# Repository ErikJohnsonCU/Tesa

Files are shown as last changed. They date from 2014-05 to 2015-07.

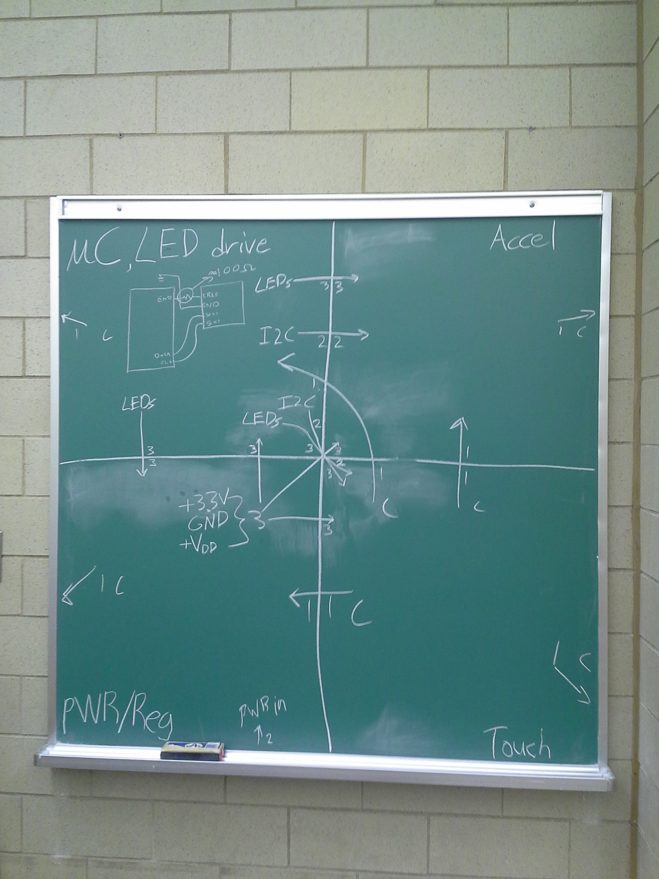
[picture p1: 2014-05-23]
Hardware/board_interconnects.jpg

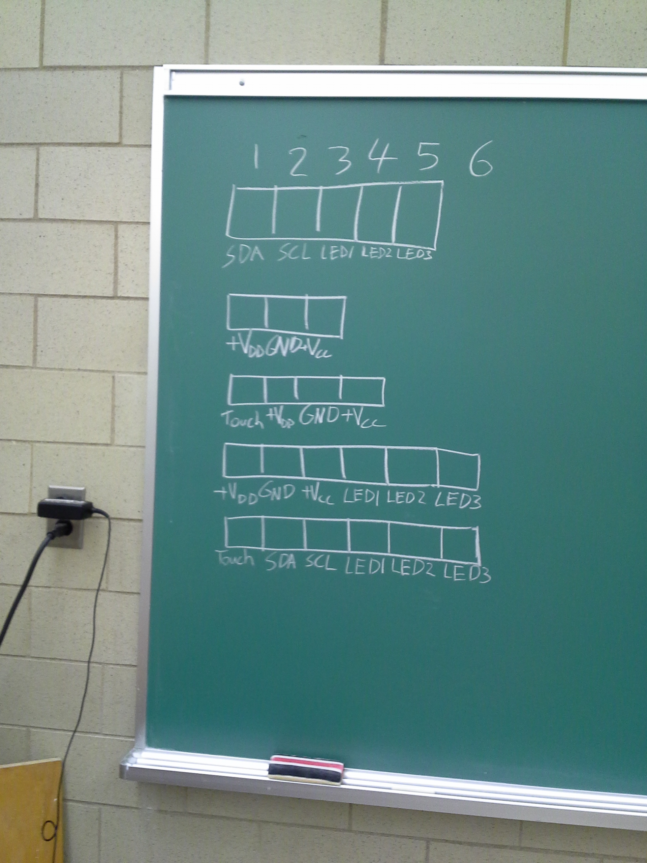
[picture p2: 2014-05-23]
Hardware/headers_order.jpg

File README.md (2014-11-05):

Tesa
====

Working board design and firmware for Tesa
==========================================

Please note I mis-ordered the 10k resistors as 2k resistors, these will still work as the value of the pull-up resistors on the reset line is very flexible.

Touch pads are numbered as follows:
Power -> 1
Micro -> 2
Accel -> 3
Touch -> 4

Leds are numbered as follows:
Micro -> 0 (rgb positions to be added)
Power -> 1 (rgb positions to be added)
Accel -> 2 (rgb positions to be added)
Touch -> 3 (rgb positions to be added)
r=3,g=2,b=1

Jumper resistor functions:
R105: connects PWRIN pin + to POWER pin 1 (use this to power uC via POWER header or distribute PWRIN pin + to other boards)
RECALL: POWER pin 1 drives LEDs
R108: connects POWER pin 3 to board's Vcc (+3.3V) (use this to run uC off external +3.3V or distribute +3.3V to other boards)

Similar work by other OH designers:
http://www.ofbrooklyn.com/2014/09/6/building-pulse-bloom-biofeedback-burning-man-2014/

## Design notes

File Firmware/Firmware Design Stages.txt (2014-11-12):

Firmware Design Stages
======================

Modular Code Development
========================
1. LED driver (shift register)
2. Touch (I2C)
3. Accelermeter (I2C)

Combination Stage
===================
1. State flow diagram
2.

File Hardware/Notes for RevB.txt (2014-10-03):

Traces
======
Signal lines: 8 mil
Power lines: 12 mil

Text
====
Header names: 50(12%)
Header designations: 36(10%)
Components: 25(8%)

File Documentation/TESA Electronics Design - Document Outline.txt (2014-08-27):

TESA Electronics Design
=======================
1.0 Motivation
2.0 Requirements
	2.1 Prototype
	2.2 Consumer Product
3.0 Prototype Design
	3.1 Hardware
		3.1.1 Microcontroller board
		3.1.2 Accelerometer board
		3.1.3 Touch driver board
		3.1.4 Power distribution board
	3.2 Firmware
4.0 Consumer Product Design
	4.1 Hardware
		4.1.1 Base discrete unit hardware
		4.1.2 Pro discrete unit hardware
		4.1.3 Hub hardware
	4.2 Firmware
		4.2.1 Base discrete unit firmware
		4.2.2 Pro discrete unit firmware
		4.2.3 Hub firmware
5.0 Project Timeline

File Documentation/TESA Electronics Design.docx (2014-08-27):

# Motivation

To fulfill a contract committed to creating a home lighting system.

# Requirements

## Prototype

- Tap-on/off capability
- Ability to connect with other units and base
- Each face supports variation in brightness
- Detection of present orientation/change in orientation

## Consumer Product

### Base Unit

- Tap-on/off capability
- Ability to connect with other units and base
- Each face supports variation in brightness
- Communication with hub and other units

### Pro Unit

- Tap-on/off capability
- Ability to connect with other units and base
- Each face supports variation in brightness
- Detection of present orientation/change in orientation
- Communication with hub and other units
- Ability to charge once connected to the hub

### Hub

- Communication with units
- Ability to charge pro units

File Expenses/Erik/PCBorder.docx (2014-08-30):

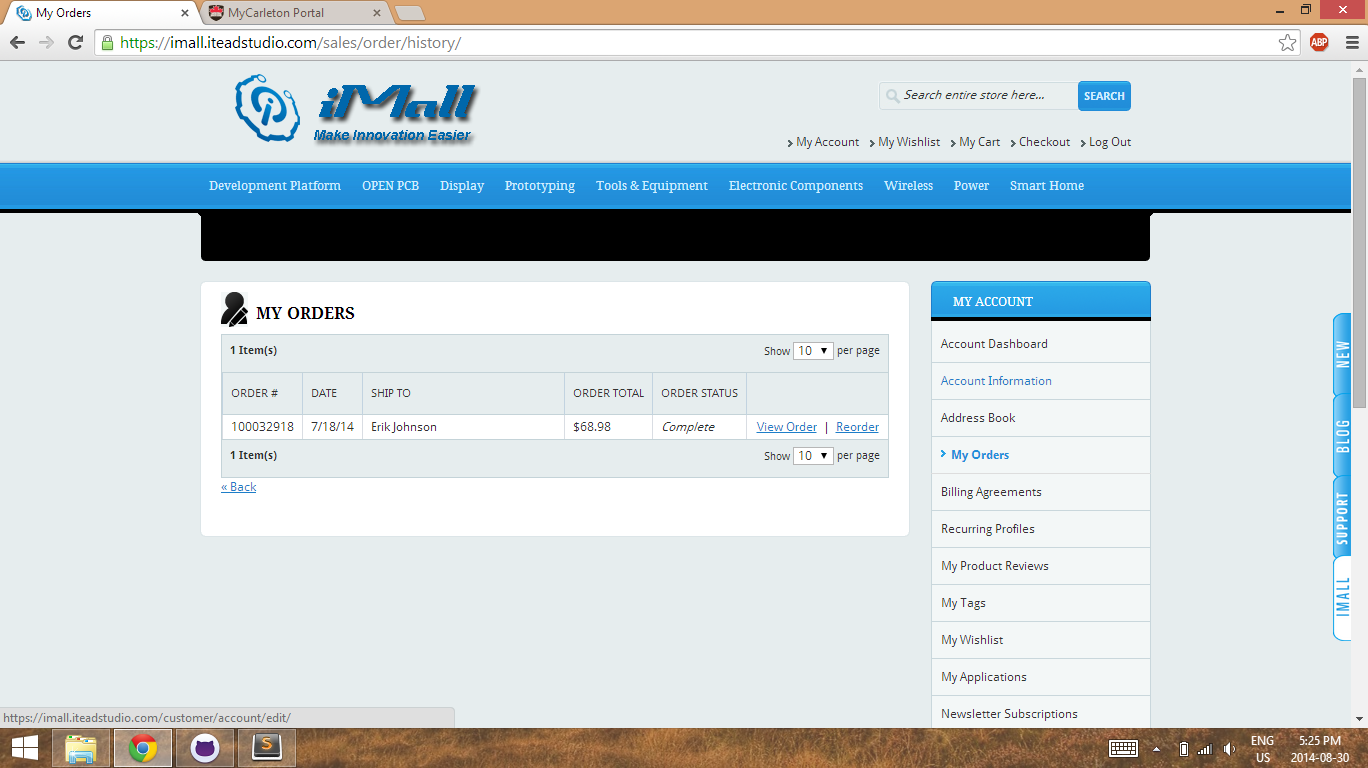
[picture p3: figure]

Expense total: $ 68.98

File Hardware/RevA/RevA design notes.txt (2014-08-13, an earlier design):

Radius of board cut is: 2.436 cm or 0.96"

Size of text is 40 (ratio 10 %) for refdes, and 60 (ratio 16 %) for header names

Size of signal traces is 8 mils
Size of power (LED, not Vcc or +3.3V) traces is 16 mils

Touch pads are numbered as follows:
Power -> 1
Micro -> 2
Accel -> 3
Touch -> 4

Leds are numbered as follows:
Power -> 0 (rgb positions to be added)
Micro -> 1 (rgb positions to be added)
Accel -> 2 (rgb positions to be added)
Touch -> 3 (rgb positions to be added)
r=3,g=2,b=1

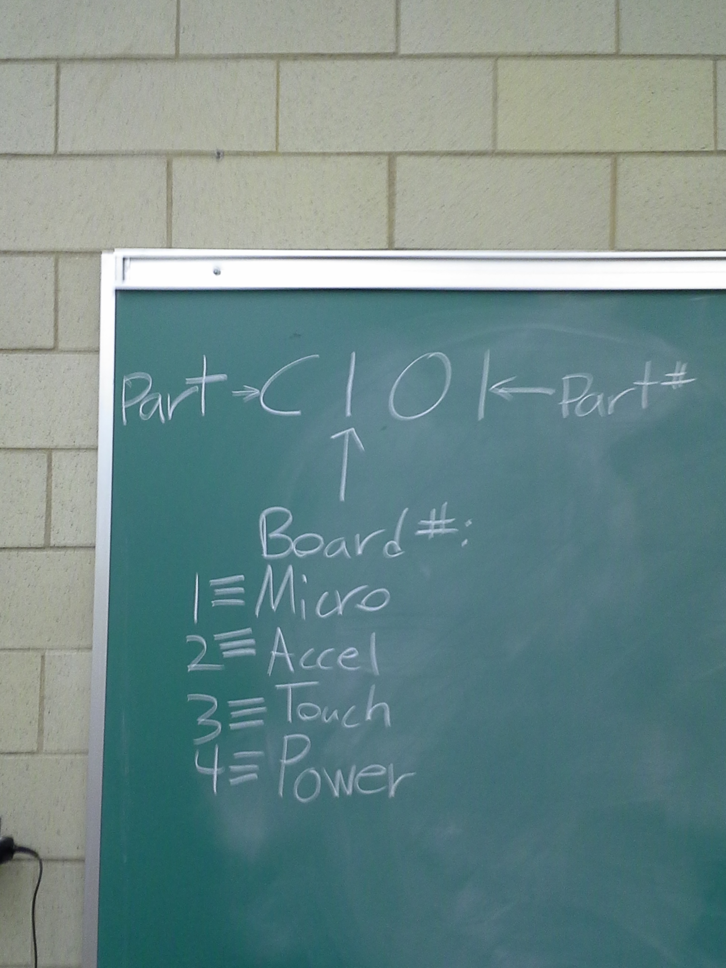
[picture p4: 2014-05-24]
Hardware/part_naming_conventions.jpg

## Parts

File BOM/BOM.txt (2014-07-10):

BOM

-AtMega32u4
-AT42QT1070
-MMA8452Q
-TLC59711
-4.7u cap
-0.1u cap x6
-1u cap x2
-4.7k res x2
-22 res x2
-MF-MSMF050-2
-1.42k (and surrounding values)
-10u cap
-the regulator
-20k res x5
-1 pin through-hole header x8
-2 pin through-hole header x2
-3 pin through-hole header x2
-4 pin through-hole header x2
-5 pin through-hole header x1
-6 pin through-hole header x2
-6 pin SMD header x4
-SMD micro USB plug

total # of headers: 43 (order 45)

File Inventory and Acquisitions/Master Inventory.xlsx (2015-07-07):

Inventory for TESA Project
Last updated: Nov. 4/14
Updated by: Erik
 |  | Resistors in ohms, capacitors in farads, fuses in amperes, resonators in Hz, regulators in volts,
Component type | Stock | Value | Refdes(es) | Footprint | Supplier | Supplier PN | Manufacturer | Manufacturer PN | Pricing (10/100/500) | Active in project? | ROHS
Capacitor | 3 | 1u | C104 | SMD_0603 | Mouser | 81-GRM188R61E105KA12 | Murata | GRM188R61E105KA12D | 0.031/0.027/0.019 | Yes | compliant
Resistor | 8 | 4.7k | R101,R102 | SMD_0603 | Mouser | 667-ERJ-3GEYJ472V | Panasonic | ERJ-3GEYJ472V | 0.014/0.01/0.007 | Yes | exemption
Fuse | 6 | 0.5A | F101 | SMD_1812 | Mouser | 652-MF-MSMF050-2 | Bourns | MF-MSMF050-2 | 0.201/0.177/0.139 | Yes
Resonator | 4 | 8M | X101 | CSTCE | Mouser | 81-CSTCE8M00G15C99R0 | Murata | CSTCE8M00G15C99-R0 | 0.503/0.477/-- | Yes | compliant
Resistor | 21 | 20k | R104,301,R302,R303,R304,R305 | SMD_0603 | Mouser | 667-ERJ-3GEYJ203V | Panasonic | ERJ-3GEYJ203V | 0.014/0.01/0.007 | Yes | exemption
Resistor | 10 | 1.4k | R103 | SMD_0603 | Mouser | 667-ERJ-3EKF1401V | Panasonic | ERJ-3EKF1401V | 0.018/0.01/0.007 | Yes | exemption
Resistor | 12 | 22 | N/A | SMD_0603 | Mouser | 667-ERJ-3GEYJ220V | Panasonic | ERJ-3GEYJ220V | 0.014/0.009/0.007 | NO (prev R105,R106) | exemption
Resistor | 10 | 1.2k | R103 | SMD_0603 | Mouser | 667-ERJ-3GEYJ122V | Panasonic | ERJ-3GEYJ122V | 0.024/0.012/0.007 | Yes | exemption
Resistor | 10 | 1.0k | R103 | SMD_0603 | Mouser | 667-ERJ-3EKF1001V | Panasonic | ERJ-3EKF1001V | 0.017/0.011/0.008 | Yes | exemption
Capacitor | 31 | 0.1u | C101,C102,C103,C107,C201,C202,C301,C401 | SMD_0603 | Mouser | 81-GRM39X104K16 | Murata | GRM188R71C104KA01D | 0.016/0.01/0.007 | Yes | compliant
Capacitor | 12 | 0.01u | N/A | SMD_0402 | Mouser | 81-GRM36X103K25 | Murata | GRM155R71E103KA01D | 0.009/0.006/0.005 | NO
Regulator | 5 | 3.3V | Q401 | TO220 | Mouser | 511-LD1117V33C | STMicroelectronics | LD1117V33C | 0.528/0.35/-- | Yes | compliant
LEDs | 70 | N/A | LED | PLCC4 | Mouser | 941-CLA1BWKWXD0F0DY3 | Cree | CLA1B-WKW-XD0F0DY3 | 0.289/0.253/0.229 | Yes | compliant
Micro-controller | 7 | N/A | U101 | TQFP44 |  |  | Atmel | AtMega32U4 |  | Yes
Touch driver | 4 | N/A | U301 | SOIC14 | Mouser | 556-AT42QT1070-SSU | Atmel | AT42QT1070-SSU | 1.77/1.27/1.19 | Yes | compliant
Accelerometer | 4 | N/A | U201 | QFN16 | Mouser | 841-MMA8452QR1 | Freescale | MMA8452QR1 | 1.48/0.965/-- | Yes | exemption
microB USB Female | 6 | N/A | N/A | N/A | Mouser | 649-10118192-0001LF | PCI | 10118192-0001LF | 0.336/0.29/0.25 | Yes | compliant
Pin headers (TH) | 14x2 | N/A | N/A | N/A | Mouser | 653-XG8S-0231 | Omron | XG8S-0231 | for 25: 0.129/0.106/0.079 | Yes | compliant
Pin headers (SMD) | 22X6 | N/A | N/A | N/A | Digikey | S1013E-06-ND | Sullins | GEC06SABN-M30 | 1.205/0.9924/0.78446 | Yes | compliant
Board | 10 | micro-A | micro (1) | N/A | Itead | N/A | N/A | N/A | N/A | Yes
Board | 10 | accel | accel (2) | N/A | Itead | N/A | N/A | N/A | N/A | Yes
Board | 12 | touch | touch (3) | N/A | Itead | N/A | N/A | N/A | N/A | Yes
Board | 11 | power | power (4) | N/A | Itead | N/A | N/A | N/A | N/A | Yes
Capacitor | 10 | 10u | C106,C203,C402 | SMD_0603 | Mouser | 963-AMK107ABJ106MAHT | Taiyo Yuden | AMK107ABJ106MAHT | 0.075/0.043/-- | Yes | compliant
LED driver | 4 | N/A | U102 | HTSSOP20 | Mouser | 595-TLC59711PWP | TI | TLC59711PWP | 4.23/3.46/2.81 | Yes | compliant
Capacitor | 11 | 10u | C106,C203,C402 | SMD_0603 | Mouser | 81-GRM18R60J475KE19D | Murata | GRM188R60J106ME47D | 0.063/0.063/-- | Yes | compliant
Capacitor | 10 | 4.7u | C203 | SMD_0603 | Mouser | 81-GRM18R60J475KE19D | Murata | GRM188R60J475KE19D | 0.063/0.035/-- | Yes | compliant
Microcontroller | 3 | N/A | U101 | TQFP_32 | Mouser | 556-ATMEGA328P-AU | Atmel | ATMEGA328P-AU | 3.64/2.74/2.58 | Yes | compliant
Resonator | 4 | 16M | X101 | CSTCE | Mouser | 81-CSTCE16M0V53-R0 | Murata | CSTCE16M0V53-R0 | 0.434/0.35/-- | Yes | compliant
Resistor | 8 | 2k (mistake) | R104 | SMD_0603 | Mouser | 71-CRCW0603-2.0K-E3 | Vishay | CRCW06032K00FKEA | 0.016/0.012/-- | Yes | exemption
Resistor | 11 | 180 | R106,R107 | SMD_0603 | Mouser | 71-CRCW0603J-180-E3 | Vishay | CRCW0603180RJNEA | 0.012/0.01/-- | Yes | exemption
Capacitor | 13 | 0.01u | C105 | SMD_0603 | Mouser | 77-VJ0603Y103KXAAC | Vishay | VJ0603Y103KXAAC | 0.06/0.036/0.03 | Yes | compliant
Resistor | 11 | 0 | R105,R108 | SMD_0603 | Mouser | 71-CRCW0603-0-E3 | Vishay | CRCW06030000Z0EA | 0.012/0.01/-- | Yes | exemption
Regulator | 3 | 3.3V | U103 | SOT-23-5 | Mouser | 595-LP2985-33DBVR | TI | LP2985-33DBVR | 0.578/0.43/0.317 | Yes | compliant
Pin Headers | 5 | N/A | N/A | N/A | Mouser | 517-9611106404AR | 3M | 961110-6404-AR | --/0.437/0.412 | Yes | compliant
Red LED | 9 | N/A | LED5 | SMD_0603 | Mouser | 710-150060RS75000 | Wurth | 150060RS75000 | 0.253/0.232/-- | Yes | compliant
Green LED | 8 | N/A | LED4 | SMD_0603 | Mouser | 710-150060VS75000 | Wurth | 150060VS75000 | 0.253/0.232/-- | Yes | compliant
Board | 19 | micro-B | micro (1) | N/A | Itead | N/A | N/A | N/A | N/A | Yes

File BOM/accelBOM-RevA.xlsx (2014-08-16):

TESA - Industrial Design Project - Summer 2014
Board: accel
Revision: A
Bill of Materials
Quantity | Refdes | Value | Footprint/Package | Specification | Supplier | Supplier PN | Manufacturer | Manufacturer PN | Price in $ (10/100/500)
1 | U201 | MMA8452Q | QFN-16 |  | Mouser | 841-MMA8452QR1 | Freescale | MMA8452QR1 | 1.44/0.857/-
1 | C203 | 4.7u | SMD_0603 |  | Mouser | 81-GRM18R60J475KE19D | Murata | GRM188R60J475KE19D | 0.061/0.035/--
2 | C201,C202 | 0.1u | SMD_0603 |  | Mouser | 81-GRM39X104K16 | Murata | GRM188R71C104KA01D | 0.023/0.018/0.015
3 | LED1,LED2,LED3 |  |  |  | Mouser | 941-CLA1BWKWXD0F0DY3 | Cree | CLA1B-WKW-XD0F0DY3 | 0.282/0.247/0.223
N/A | TH hdr | 12 pins |  |  | Mouser | 653-XG8S-0231 | Omron | XG8S-0231 | for 25: 0.129/0.106/0.079

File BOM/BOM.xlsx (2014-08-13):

Micro |  | Accel |  | Touch |  | Power
Refdes | Part | Refdes | Part | Refdes | Part | Refdes | Part
U101 | AtMega32U4 | U201 | MMA8452Q | U301 | AT42QT1070 | Q401
R101 | 4.7k | C201 | 0.1u | R301 | 20k | C401 | 0.1u
R102 | 4.7k | C202 | 0.1u | R302 | 20k | C402 | 10u
R103 | 1.42k (or close value) | C203 | 4.7u | R303 | 20k | 1pin TH hdr | 16pin hdr total
R104 | 22 | LED1 |  | R304 | 20k | 2pin TH hdr
R105 | 22 | LED2 |  | R305 | 20k | 3pin TH hdr
F101 | MF-MSMF050-2 (check rating) | LED3 |  | C301 | 0.1u | 4pin TH hdr
C101 | 0.1u | 1pin TH hdr | 12pin hdr total | LED1 |  | 6pin TH hdr
C102 | 1u | 1pin TH hdr |  | LED2
C103 | 1u | 2pin TH hdr |  | LED3
C104 | 0.1u | 3pin TH hdr |  | 1pin TH hdr | 13pin hdr total
X101 | CSTCE8M00G55-R0 | 5pin TH hdr |  | 1pin TH hdr
LED1 |  |  |  | 1pin TH hdr
LED2 |  |  |  | 4pin TH hdr
LED3 |  |  |  | 6pin Th hdr
uB USB plug
6pin SMD hdr
6pin SMD hdr
6pin SMD hdr
6pin SMD hdr
1pin TH hdr
U102 | TLC59711

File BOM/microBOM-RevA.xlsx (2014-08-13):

TESA - Industrial Design Project - Summer 2014
Board: micro
Revision: A
Bill of Materials
Quantity | Refdes | Value | Footprint/Package | Specification | Supplier | Supplier PN | Manufacturer | Manufacturer PN | Price in $ (10/100/500)
1 | U101 | AtMega32U4 | TQFP-44 |  |  |  | Atmel | AtMega32U4
2 | R101,R102 | 4.7k | SMD_0603 |  | Mouser | 667-ERJ-3GEYJ472V | Panasonic | ERJ-3GEYJ472V | 0.014/0.009/0.007
1 | R103 | 1k | SMD_0603 |  | Mouser | 667-ERJ-3EKF1001V | Panasonic | ERJ-3EKF1001V | 0.016/0.011/0.008
1 | R103 | 1.2k | SMD_0603 |  | Mouser | 667-ERJ-3GEYJ122V | Panasonic | ERJ-3GEYJ122V | 0.023/0.012/0.007
1 | R103 | 1.4k | SMD_0603 |  | Mouser | 667-ERJ-3EKF1401V | Panasonic | ERJ-3EKF1401V | 0.018/0.009/0.007
1 | R103 | 1.6k | SMD_0603 |  | Mouser | 667-ERJ-3GEYJ162V | Panasonic | ERJ-3GEYJ162V | 0.023/0.012/0.007
1 | R103 | 1.8k | SMD_0603 |  | Mouser | 667-ERJ-3GEYJ182V | Panasonic | ERJ-3GEYJ182V | 0.023/0.012/0.007
2 | R104,R105 | 22 | SMD_0603 |  | Mouser | 667-ERJ-3GEYJ220V | Panasonic | ERJ-3GEYJ220V | 0.014/0.009/0.007
1 | F101 | MF-MSMF050-2 | SMD_1812 | 1A trip | Mouser | 652-MF-MSMF050-2 | Bourns | MF-MSMF050-2 | 0.201/0.177/0.139
2 | C101,C104 | 0.1u | SMD_0603 |  | Mouser | 81-GRM39X104K16 | Murata | GRM188R71C104KA01D | 0.023/0.018/0.015
2 | C102,C103 | 1u | SMD_0603 |  | Mouser | 81-GRM188R61E105KA12 | Murata | GRM188R61E105KA12D | 0.031/0.026/0.019
1 | X101 | CSTCE8M00G55-R0 | CSTCE |  | Mouser | 81-CSTCE8M00G15C99R0 | Murata | CSTCE8M00G15C99-R0 | 0.49/0.465/--
3 | LED1,LED2,LED3 |  | PLCC-4 |  | Mouser | 941-CLA1BWKWXD0F0DY3 | Cree | CLA1B-WKW-XD0F0DY3 | 0.282/0.247/0.223
1 | uB USB Female |  |  |  | Mouser | 649-10118192-0001LF | PCI | 10118192-0001LF | 0.336/0.29/0.25
4 | 6 pin SMD hdr |  |  |  | Digikey | S1013E-06-ND | Sullins | GEC06SABN-M30 | 1.205/0.9924/0.78446
N/A | TH hdr | 1 pin |  |  | Mouser | 653-XG8S-0231 | Omron | XG8S-0231 | for 25: 0.129/0.106/0.079
1 | U102 | TLC59711 | HTSSOP-20 |  | Mouser | 595-TLC59711PWP | TI | TLC59711PWP | 4.12/3.37/2.47

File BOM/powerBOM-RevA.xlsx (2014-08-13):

TESA - Industrial Design Project - Summer 2014
Board: power
Revision: A
Bill of Materials
Quantity | Refdes | Value | Footprint/Package | Specification | Supplier | Supplier PN | Manufacturer | Manufacturer PN | Price in $ (10/100/500)
1 | Q401 | 3.3V | LD1117-TO-220 |  | Mouser | 511-LD1117V33C | STMicroelectronics | LD1117V33C | 0.775/0.514/0.341
1 | C401 | 0.1u | SMD_0603 |  | Mouser | 81-GRM39X104K16 | Murata | GRM188R71C104KA01D | 0.023/0.018/0.015
1 | C402 | 10u | SMD_0603 |  | Mouser | 81-GRM188R60J106ME47 | Murata | GRM188R60J106ME47D | 0.225/0.135/--
3 | LED1,LED2,LED3 |  |  |  | Mouser | 941-CLA1BWKWXD0F0DY3 | Cree | CLA1B-WKW-XD0F0DY3 | 0.282/0.247/0.223
N/A | TH hdr | 16 pins |  |  | Mouser | 653-XG8S-0231 | Omron | XG8S-0231 | for 25: 0.129/0.106/0.079

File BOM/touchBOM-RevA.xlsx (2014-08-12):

TESA - Industrial Design Project - Summer 2014
Board: touch
Revision: A
Bill of Materials
Quantity | Refdes | Value | Footprint/Package | Specification | Supplier | Supplier PN | Manufacturer | Manufacturer PN | Price in $ (10/100/500)
1 | U301 | AT42QT1070 | SOIC-14 |  | Mouser | 556-AT42QT1070-SSU | Atmel | AT42QT1070-SSU | 1.55/0.969/-
5 | R301,R302,R303,R304,R305 | 20k | SMD_0603 |  | Mouser | 667-ERJ-3GEYJ203V | Panasonic | ERJ-3GEYJ203V | 0.014/0.009/0.007
1 | C301 | 0.1u | SMD_0603 |  | Mouser | 81-GRM39X104K16 | Murata | GRM188R71C104KA01D | 0.023/0.018/0.015
3 | LED1,LED2,LED3 |  |  |  | Mouser | 941-CLA1BWKWXD0F0DY3 | Cree | CLA1B-WKW-XD0F0DY3 | 0.282/0.247/0.223
N/A | TH hdr | 13 pins |  |  | Mouser | 653-XG8S-0231 | Omron | XG8S-0231 | for 25: 0.129/0.106/0.079

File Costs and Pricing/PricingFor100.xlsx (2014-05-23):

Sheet: Without USB
Price (per unit for 100) | Price (extended) | Description | Part | Quantity (for 100 units) | Supplier | Supplier ref | Schem ref des
1.93 | 193 | Micro Controller | ATMega328 | 100 | Mouser | 556-ATMEGA328-AU
0.99 | 99 | Touch sensor | AT42QT1070 | 100 | Mouser | 556-AT42QT1070-SSU
2.94 | 294.35 | LED driver | TLC59711 | 100 | Digikey | 296-36745-1-ND
2.64 | 264 | LEDs | CLA1B-WKW-XD0F0E33 | 1200 | Digikey | CLA1B-WKW-XD0F0E33TR-ND
2.5 | 100 | PCBs |  | 400 | ITEAD | N/A
0.876 | 87.6 | Accelerometer | MMA8452QR1 | 100 | Mouser | 841-MMA8452QR1
Price of Unit | Price of 100 Units
11.876 | 1037.95

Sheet: With USB
Price (per unit for 100) | Price (extended) | Description | Part | Quantity (for 100 units) | Supplier | Supplier ref | Schem ref des
4.21 | 421 | MicroController (USB capable) | AtMega32U4-AU | 100 | Mouser | 556-ATMEGA32U4-AU
0.99 | 99 | Touch sensor | AT42QT1070 | 100 | Mouser | 556-AT42QT1070-SSU
2.94 | 294.35 | LED driver | TLC59711 | 100 | Digikey | 296-36745-1-ND
2.64 | 264 | LEDs | CLA1B-WKW-XD0F0E33 | 1200 | Digikey | CLA1B-WKW-XD0F0E33TR-ND
2.5 | 100 | PCBs |  | 400 | ITEAD | N/A
0.876 | 87.6 | Accelerometer | MMA8452QR1 | 100 | Mouser | 841-MMA8452QR1
Price of Unit | Price of 100 Units
14.156 | 1265.95

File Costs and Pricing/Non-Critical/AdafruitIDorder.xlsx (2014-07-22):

Item | Use | Price (for indicated quantity) | Adafruit ref
TLC59711 - LED Driver SPI | PWM LED Driver w/ 16 bit res | 7.5 | 1455
Trinket - Mini MCU 3.3V logic | Prototype MCU | 7.95 | 1500
Tilt ball switch | Possibly bets than accel (cheaper) | 2 | 173
Piezo element | Possibly tap detection? | 0.95 | 1739
 | Subtotal | 18.4
 | TOTAL PRICE (w taxes and shipping) | ~25

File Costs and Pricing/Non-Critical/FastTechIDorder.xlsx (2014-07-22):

Item | Use | Price (for indicated quantity) | FastTech ref
Tap/Knock Sensor | Tap detection | 6.72 | 1585704
 | Subtotal | 6.72
 | TOTAL PRICE (w taxes and shipping)

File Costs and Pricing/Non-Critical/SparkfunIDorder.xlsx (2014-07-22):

Item | Use | Price (for indicated quantity) | Sparkfun ref
TLC 5940 - PWM Driver | For driving the leds | 5.95 | COM10136
LED RGB clear x2 | Lighting | 3.9 | COM00105
LED RGB diffuse x2 | Lighting | 3.9 | COM09264
Piezo element | Possibly tap sensor? | 1.5 | SEN10293
AVR 8 pin ATtiny85 | Cheap MCU | 2.84 | COM09378
MMA8452Q accel breakout | Gravity sensing | 9.95 | SEN10955
AVR 14 pin ATtiny84 | Cheap MCU | 2.95 | COM11232
 | Subtotal | 30.99
 | TOTAL PRICE (w taxes and shipping) | 30.99

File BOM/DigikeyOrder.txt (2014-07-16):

DigiKey

Product Number			Quantity
S1013E-06-ND			24
MCP6002-I/P-ND			3

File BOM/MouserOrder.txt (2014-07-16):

Mouser

Product Number			Quantity
556-AT42QT1070-SSU		6
667-ERJ-3GEYJ203V		30
81-GRM39X104K16			42
941-CLA1BWKWXD0F0DY3		72
667-ERJ-3GEYJ472V		12
667-ERJ-3GEYJ220V		12
652-MF-MSMF050-2		6
81-GRM188R61E105KA12		12
81-CSTCE8M00G15C99R0		10
649-10118192-0001LF		6
653-XG8S-0231			14
841-MMA8452QR1			6
81-GRM36X103K25			12
511-LD1117V33C			6
667-ERJ-U03F1001V		10
667-ERJ-3GEYJ122V		10
667-ERJ-3EKF1401V		10
667-ERJ-3GEYJ162V		10
667-ERJ-3GEYJ182V		10

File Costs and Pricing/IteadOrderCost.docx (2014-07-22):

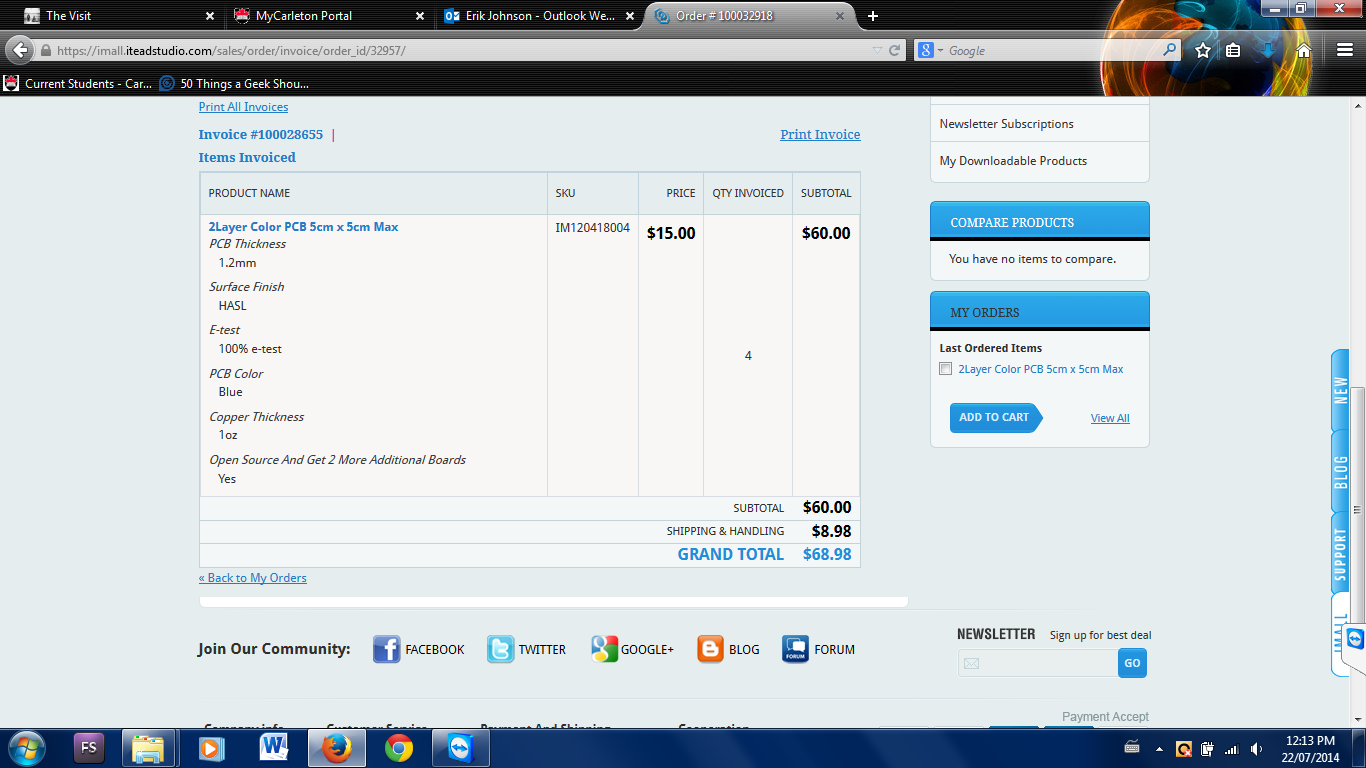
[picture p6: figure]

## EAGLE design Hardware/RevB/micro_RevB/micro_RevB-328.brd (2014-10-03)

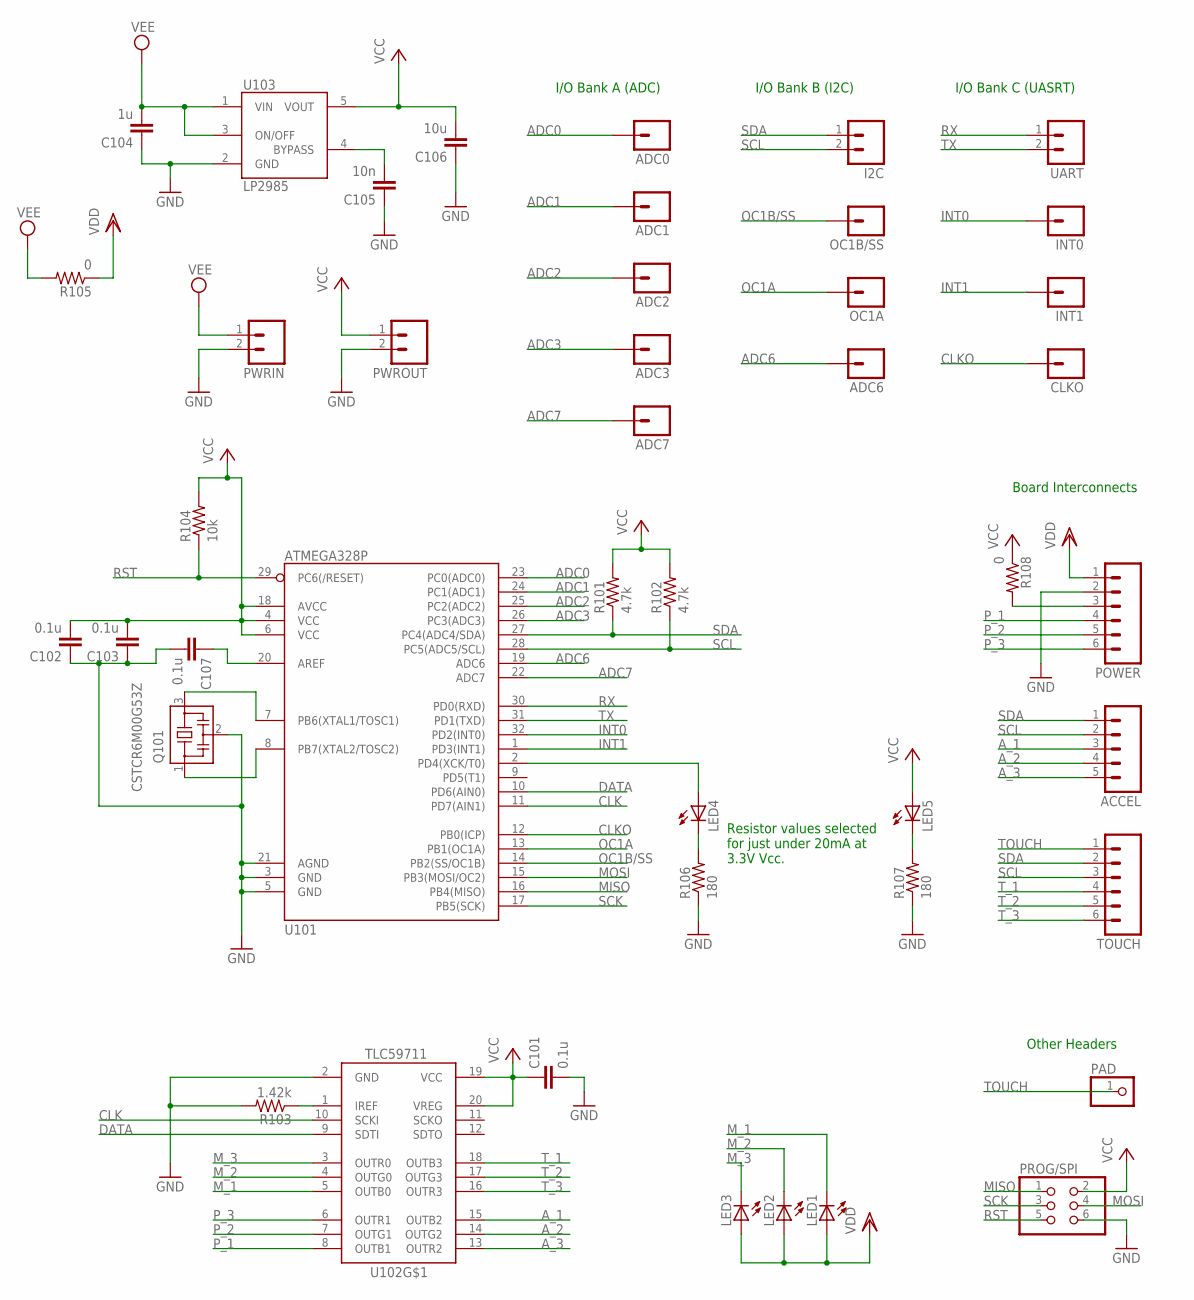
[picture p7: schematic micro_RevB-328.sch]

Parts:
ACCEL: M05LOCK; 1X05_LOCK
ADC0, ADC1, ADC2, ADC3, ADC6, ADC7: M01PTH; 1X01
C101, C102, C103, C107: 0.1u; C0603
C104: 1u; C0603
C105: 10n; C0603
C106: 10u; C0603
CLKO: M01PTH; 1X01
I2C: M02LOCK; 1X02_LOCK
INT0, INT1: M01PTH; 1X01
LED1, LED2, LED3: LEDP-LCC-4; P-LCC-4
LED4, LED5: LEDSML0603; SML0603
OC1A, OC1B/SS: M01PTH; 1X01
PAD: PINHD-1X1; 1X01
POWER: M06SIP_LOCK; 1X06-SIP_LOCK
PROG/SPI: PINHD-2X3; 2X03
PWRIN: M02LOCK; 1X02_LOCK
PWROUT: M02LOCK; 1X02_LOCK
Q101: CSTCR6M00G53Z; CSTCR6M
R101, R102: 4.7k; R0603
R103: 1.42k; R0603
R104: 10k; R0603
R105, R108: 0; R0603
R106, R107: 180; R0603
TOUCH: M06SIP_LOCK; 1X06-SIP_LOCK
U101: ATMEGA328P; TQFP32-08
U102: TLC59711; HTSSOP20DAP
U103: LP2985AIM5-3.3; SOT25
UART: M02LOCK; 1X02_LOCK

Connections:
ADC0: ADC0.1, U101.23 (PC0(ADC0))
ADC1: ADC1.1, U101.24 (PC1(ADC1))
ADC2: ADC2.1, U101.25 (PC2(ADC2))
ADC3: ADC3.1, U101.26 (PC3(ADC3))
ADC6: ADC6.1, U101.19 (ADC6)
ADC7: ADC7.1, U101.22 (ADC7)
A_1: ACCEL.3, U102.15 (OUTB2)
A_2: ACCEL.4, U102.14 (OUTG2)
A_3: ACCEL.5, U102.13 (OUTR2)
BYPASS: C105.2, U103.4 (BYPASS)
CLK: U101.11 (PD7(AIN1)), U102.10 (SCKI)
CLKO: CLKO.1, U101.12 (PB0(ICP))
DATA: U101.10 (PD6(AIN0)), U102.9 (SDTI)
INT0: INT0.1, U101.32 (PD2(INT0))
INT1: INT1.1, U101.1 (PD3(INT1))
MISO: PROG/SPI.1, U101.16 (PB4(MISO))
MOSI: PROG/SPI.4, U101.15 (PB3(MOSI/OC2))
M_1: LED1.C@4 (C), U102.5 (OUTB0)
M_2: LED2.C@4 (C), U102.4 (OUTG0)
M_3: LED3.C@4 (C), U102.3 (OUTR0)
N7: C101.2, C102.1, C103.1, C104.1, C105.1, C106.1, C107.2, POWER.2, PROG/SPI.6, PWRIN.2, PWROUT.2, Q101.2, R103.2, R106.1, R107.1, U101.3 (GND), U101.5 (GND), U101.21 (AGND), U102.2 (GND), U103.2 (GND)
unnamed: Q101.1, U101.8 (PB7(XTAL2/TOSC2))
unnamed: Q101.3, U101.7 (PB6(XTAL1/TOSC1))
unnamed: LED4.A, U101.2 (PD4(XCK/T0))
unnamed: R103.1, U102.1 (IREF)
unnamed: POWER.3, R108.2
unnamed: LED4.C, R106.2
unnamed: C107.1, U101.20 (AREF)
unnamed: LED5.C, R107.2
OC1A: OC1A.1, U101.13 (PB1(OC1A))
OC1B/SS: OC1B/SS.1, U101.14 (PB2(SS/OC1B))
P_1: POWER.4, U102.8 (OUTB1)
P_2: POWER.5, U102.7 (OUTG1)
P_3: POWER.6, U102.6 (OUTR1)
RST: PROG/SPI.5, R104.1, U101.29 (PC6(/RESET))
RX: U101.30 (PD0(RXD)), UART.1
SCK: PROG/SPI.3, U101.17 (PB5(SCK))
SCL: ACCEL.2, I2C.2, R102.1, TOUCH.3, U101.28 (PC5(ADC5/SCL))
SDA: ACCEL.1, I2C.1, R101.1, TOUCH.2, U101.27 (PC4(ADC4/SDA))
TOUCH: PAD.1, TOUCH.1
TX: U101.31 (PD1(TXD)), UART.2
T_1: TOUCH.4, U102.18 (OUTB3)
T_2: TOUCH.5, U102.17 (OUTG3)
T_3: TOUCH.6, U102.16 (OUTR3)
VCC: C101.1, C102.2, C103.2, C106.2, LED5.A, PROG/SPI.2, PWROUT.1, R101.2, R102.2, R104.2, R108.1, U101.4 (VCC), U101.6 (VCC), U101.18 (AVCC), U102.19 (VCC), U102.20 (VREG), U103.5 (VOUT)
VDD: LED1.A, LED2.A, LED3.A, POWER.1, R105.1
VEE: C104.2, PWRIN.1, R105.2, U103.1 (VIN), U103.3 (ON/OFF)

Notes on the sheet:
I/O Bank A (ADC)
I/O Bank B (I2C)
I/O Bank C (UASRT)
Resistor values selected for just under 20mA at 3.3V Vcc.
Board Interconnects
Other Headers

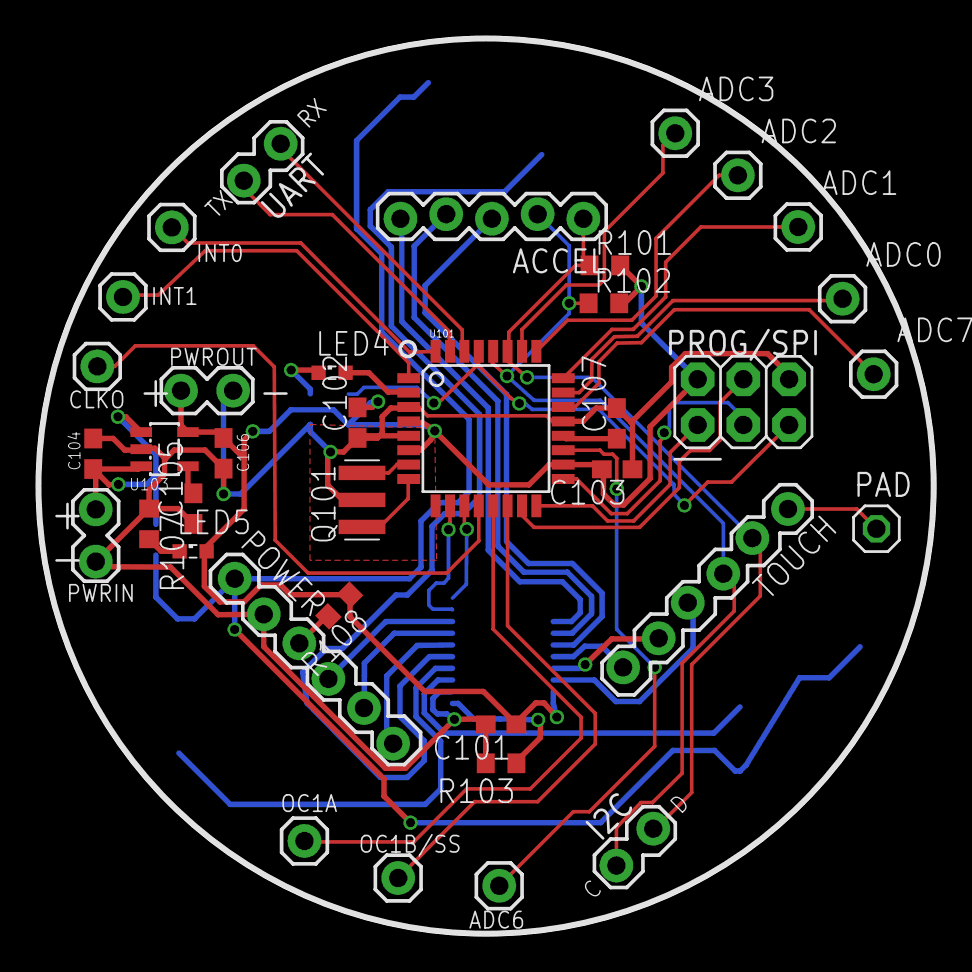
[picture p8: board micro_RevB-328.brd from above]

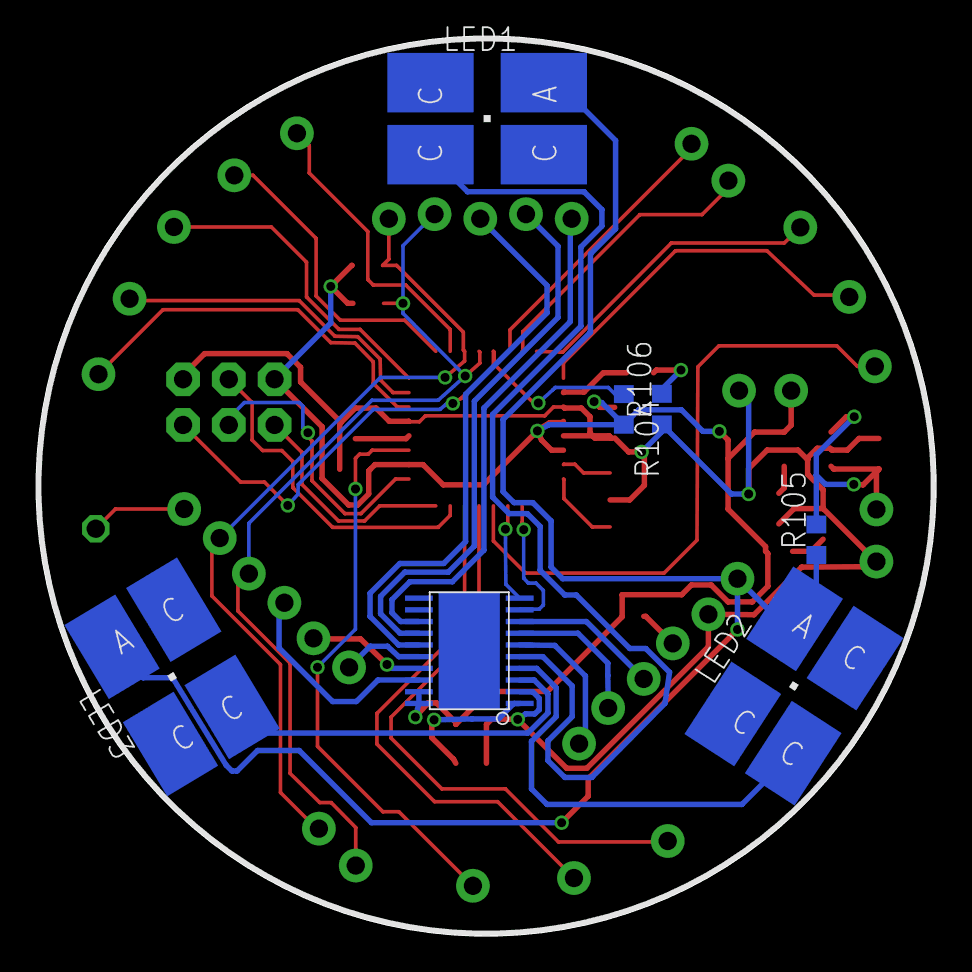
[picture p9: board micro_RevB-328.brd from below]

Board: 2 copper layers, 50.0 x 50.0 mm, 44 parts (7 on the bottom side), 47 nets.

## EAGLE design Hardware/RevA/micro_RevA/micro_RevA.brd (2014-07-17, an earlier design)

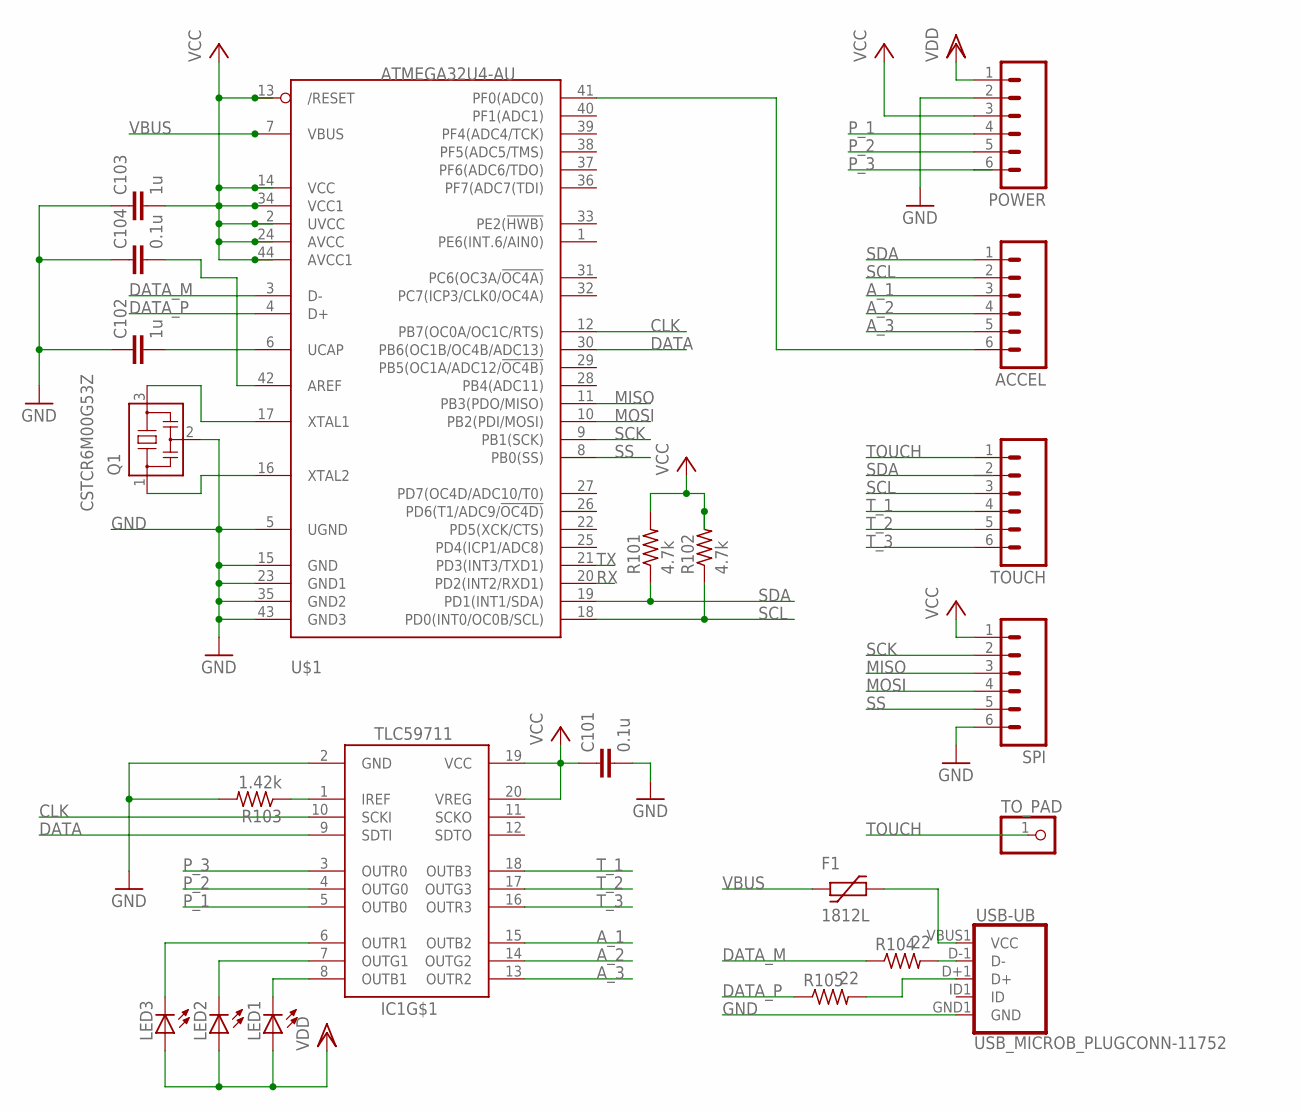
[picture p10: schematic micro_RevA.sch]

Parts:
ACCEL: M06SMD-STRAIGHT-ALT; 1X06_SMD_STRAIGHT_ALT
C101, C104: 0.1u; C0603
C102, C103: 1u; C0603
F1: 1812L
IC1: TLC59711; HTSSOP20DAP
LED1, LED2, LED3: LEDP-LCC-4; P-LCC-4
POWER: M06SMD-STRAIGHT-ALT; 1X06_SMD_STRAIGHT_ALT
Q1: CSTCR6M00G53Z; CSTCR6M
R101, R102: 4.7k; R0603
R103: 1.42k; R0603
R104, R105: 22; R0603
SPI: M06SMD-STRAIGHT-ALT; 1X06_SMD_STRAIGHT_ALT
TOUCH: M06SMD-STRAIGHT-ALT; 1X06_SMD_STRAIGHT_ALT
TO_PAD: PINHD-1X1; 1X01
U$1: ATMEGA32U4-AU; TQFP44
USB-UB: USB_MICROB_PLUGCONN-11752; USB-B-MICRO-SMD_V03

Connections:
A_1: ACCEL.3, IC1.15 (OUTB2)
A_2: ACCEL.4, IC1.14 (OUTG2)
A_3: ACCEL.5, IC1.13 (OUTR2)
CLK: IC1.10 (SCKI), U$1.12 (PB7(OC0A/OC1C/RTS))
DATA: IC1.9 (SDTI), U$1.30 (PB6(OC1B/OC4B/ADC13))
DATA_M: R104.1, U$1.3 (D-)
DATA_P: R105.1, U$1.4 (D+)
GND: C101.2, C102.1, C103.1, C104.1, IC1.2 (GND), POWER.2, Q1.2, R103.2, SPI.6, U$1.5 (UGND), U$1.15 (GND), U$1.23 (GND1), U$1.35 (GND2), U$1.43 (GND3), USB-UB.GND1 (GND)
MISO: SPI.3, U$1.11 (PB3(PDO/MISO))
MOSI: SPI.4, U$1.10 (PB2(PDI/MOSI))
unnamed: Q1.3, U$1.17 (XTAL1)
unnamed: Q1.1, U$1.16 (XTAL2)
unnamed: C104.2, U$1.42 (AREF)
unnamed: IC1.1 (IREF), R103.1
unnamed: IC1.6 (OUTR1), LED3.C@4 (C)
unnamed: IC1.7 (OUTG1), LED2.C@4 (C)
unnamed: IC1.8 (OUTB1), LED1.C@4 (C)
unnamed: C102.2, U$1.6 (UCAP)
unnamed: ACCEL.6, U$1.41 (PF0(ADC0))
unnamed: R104.2, USB-UB.D-1 (D-)
unnamed: R105.2, USB-UB.D+1 (D+)
unnamed: F1.P$2 (2), USB-UB.VBUS1 (VCC)
P_1: IC1.5 (OUTB0), POWER.4
P_2: IC1.4 (OUTG0), POWER.5
P_3: IC1.3 (OUTR0), POWER.6
RX: U$1.20 (PD2(INT2/RXD1))
SCK: SPI.2, U$1.9 (PB1(SCK))
SCL: ACCEL.2, R102.1, TOUCH.3, U$1.18 (PD0(INT0/OC0B/SCL))
SDA: ACCEL.1, R101.1, TOUCH.2, U$1.19 (PD1(INT1/SDA))
SS: SPI.5, U$1.8 (PB0(SS))
TOUCH: TOUCH.1, TO_PAD.1
TX: U$1.21 (PD3(INT3/TXD1))
T_1: IC1.18 (OUTB3), TOUCH.4
T_2: IC1.17 (OUTG3), TOUCH.5
T_3: IC1.16 (OUTR3), TOUCH.6
VBUS: F1.P$1 (1), U$1.7 (VBUS)
VCC: C101.1, C103.2, IC1.19 (VCC), IC1.20 (VREG), POWER.3, R101.2, R102.2, SPI.1, U$1.2 (UVCC), U$1.13 (/RESET), U$1.14 (VCC), U$1.24 (AVCC), U$1.34 (VCC1), U$1.44 (AVCC1)
VDD: LED1.A, LED2.A, LED3.A, POWER.1

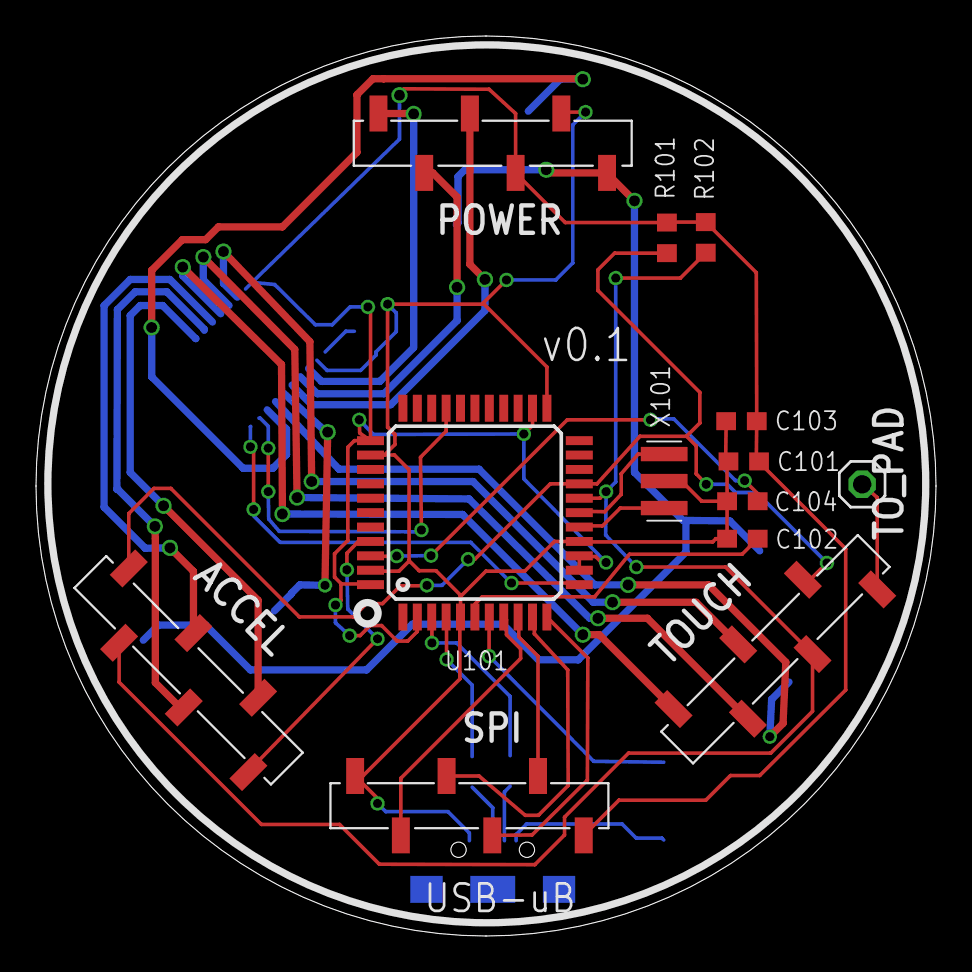
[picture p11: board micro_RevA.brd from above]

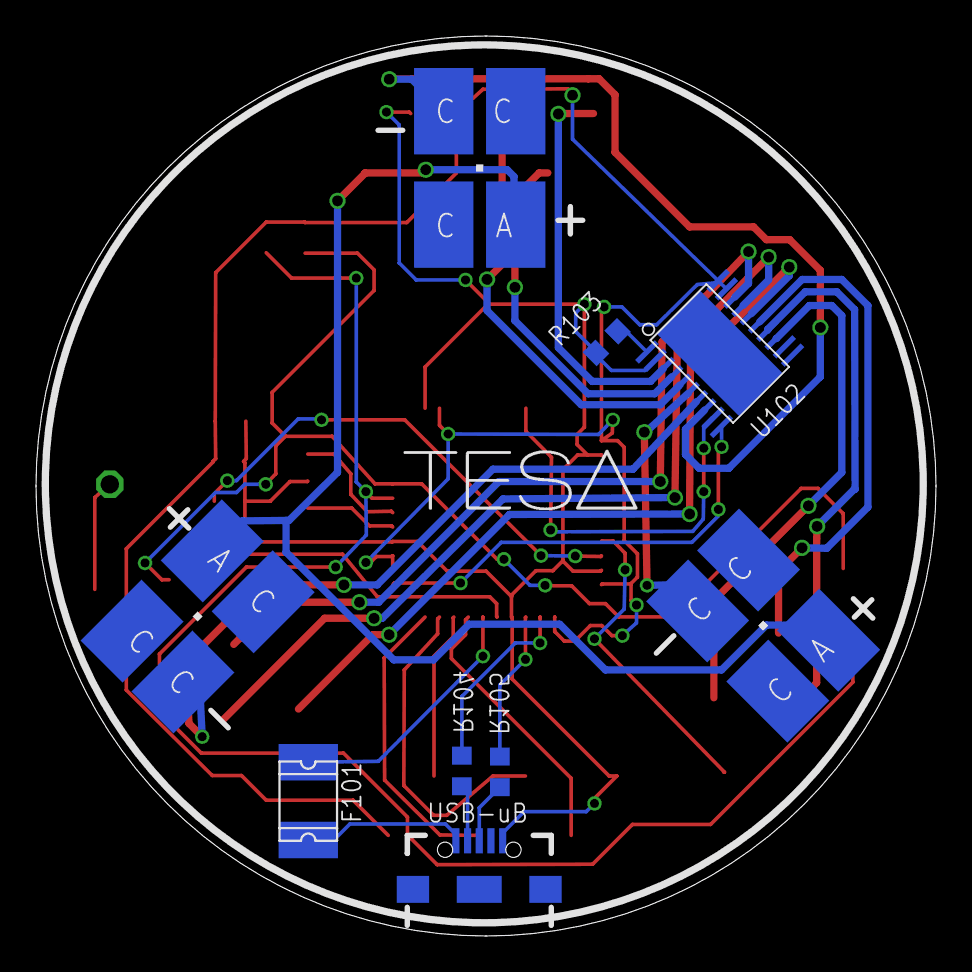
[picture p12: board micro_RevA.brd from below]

Board: 2 copper layers, 50.0 x 50.0 mm, 22 parts (9 on the bottom side), 36 nets.

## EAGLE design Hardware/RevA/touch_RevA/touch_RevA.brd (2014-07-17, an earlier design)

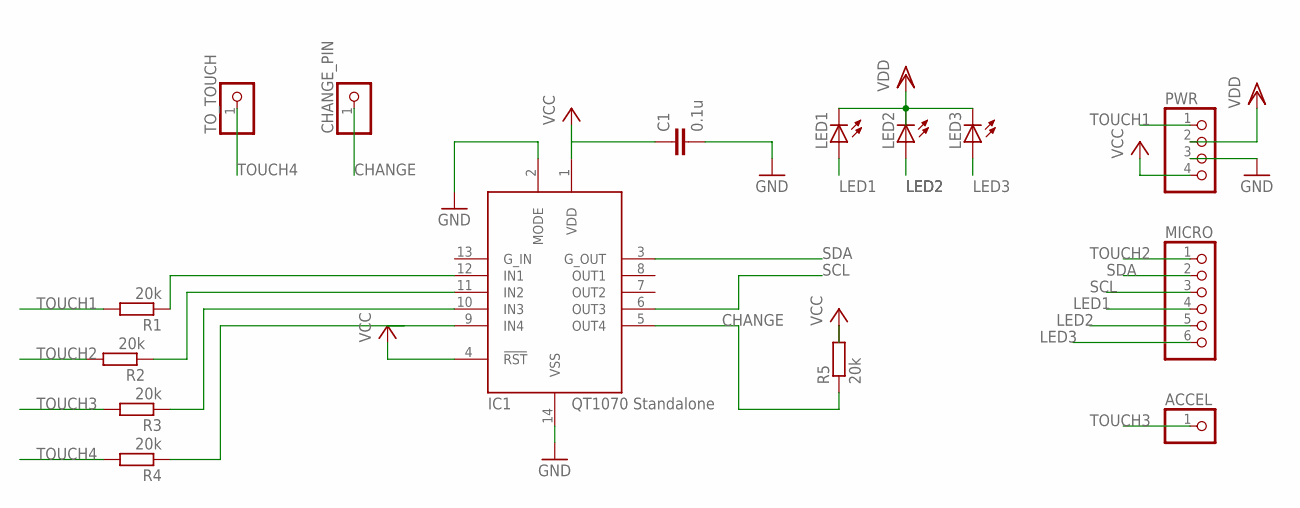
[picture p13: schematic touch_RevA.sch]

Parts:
ACCEL: PINHD-1X1; 1X01
C1: 0.1u; C0603
CHANGE_PIN: PINHD-1X1; 1X01
IC1: AT42QT1070-SSU; SO14
LED1, LED2, LED3: LEDP-LCC-4; P-LCC-4
MICRO: PINHD-1X6; 1X06
PWR: PINHD-1X4; 1X04
R1, R2, R3, R4, R5: 20k; R0603
TO_TOUCH: PINHD-1X1; 1X01

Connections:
CHANGE: CHANGE_PIN.1, IC1.5 (OUT4), R5.1
GND: C1.2, IC1.2 (MODE), IC1.14 (VSS), PWR.3
LED1: LED1.A, MICRO.4
LED2: LED2.A, MICRO.5
LED3: LED3.A, MICRO.6
unnamed: IC1.12 (IN1), R1.1
unnamed: IC1.11 (IN2), R2.1
unnamed: IC1.10 (IN3), R3.1
unnamed: IC1.9 (IN4), R4.1
SCL: IC1.6 (OUT3), MICRO.3
SDA: IC1.3 (G_OUT), MICRO.2
TOUCH1: PWR.1, R1.2
TOUCH2: MICRO.1, R2.2
TOUCH3: ACCEL.1, R3.2
TOUCH4: R4.2, TO_TOUCH.1
VCC: C1.1, IC1.1 (VDD), IC1.4 (!RST), PWR.4, R5.2
VDD: LED1.C@4 (C), LED2.C@4 (C), LED3.C@4 (C), PWR.2

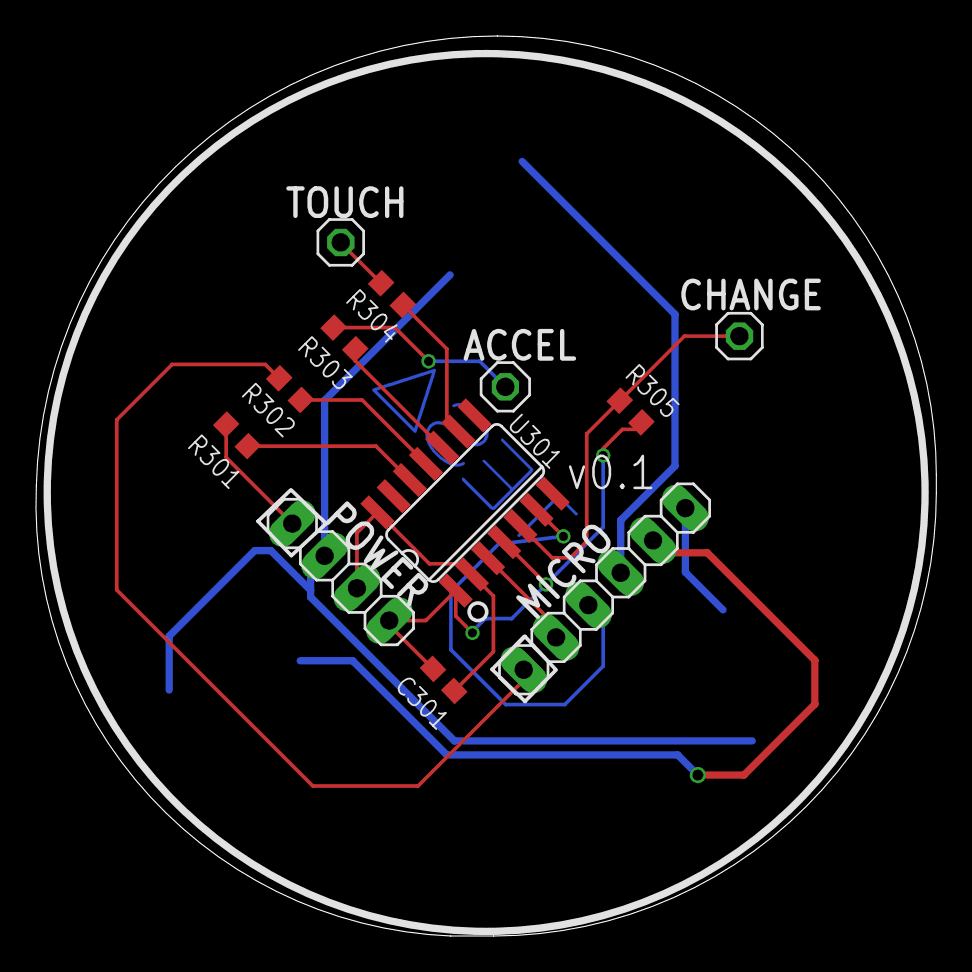
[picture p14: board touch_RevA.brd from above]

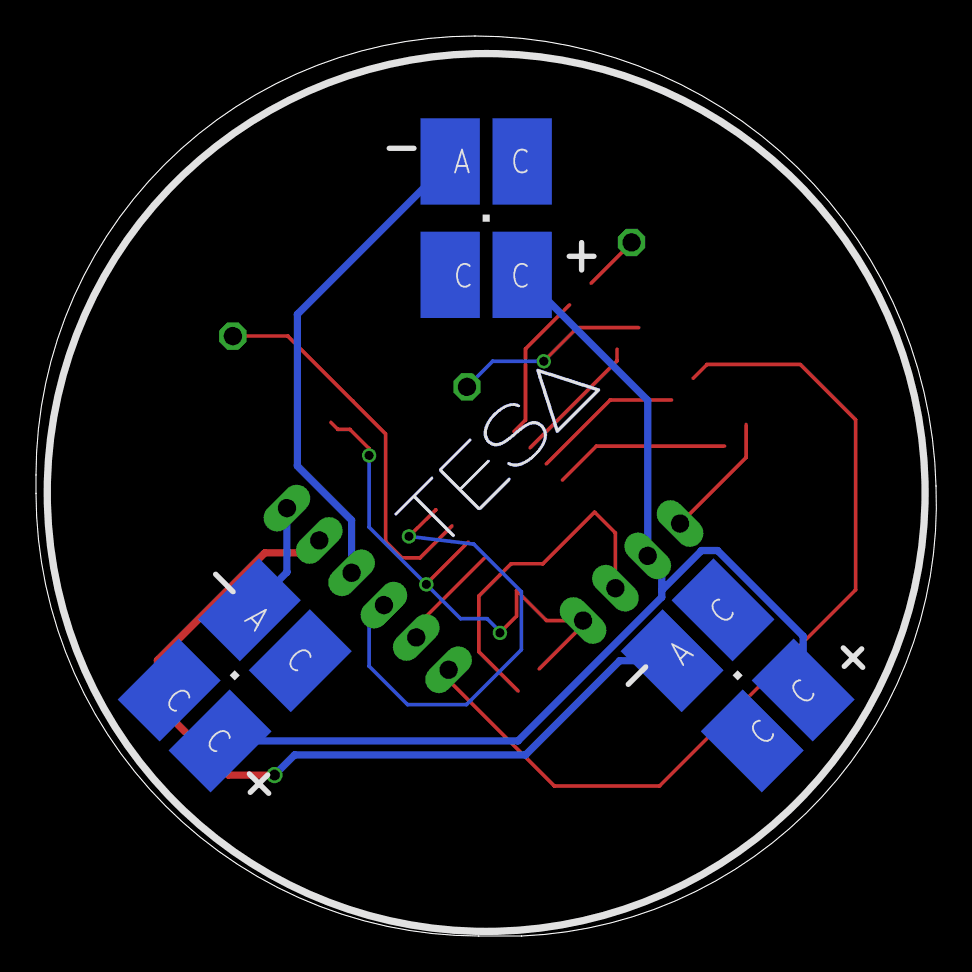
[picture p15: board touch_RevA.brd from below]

Board: 2 copper layers, 50.0 x 50.0 mm, 15 parts (3 on the bottom side), 17 nets.

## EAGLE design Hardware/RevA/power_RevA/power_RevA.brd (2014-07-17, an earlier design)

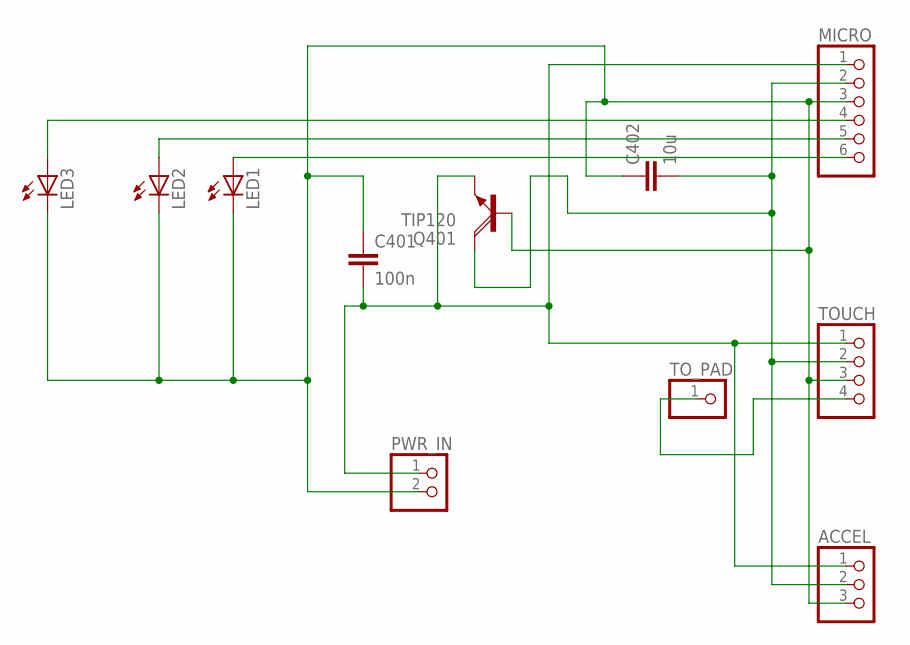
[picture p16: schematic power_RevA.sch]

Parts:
ACCEL: PINHD-1X3; 1X03
C401: 100n; C0603
C402: 10u; C0603
LED1, LED2, LED3: LEDP-LCC-4; P-LCC-4
MICRO: PINHD-1X6; 1X06
PWR_IN: PINHD-1X2; 1X02
Q401: TIP120; TO220AH
TOUCH: PINHD-1X4; 1X04
TO_PAD: PINHD-1X1; 1X01

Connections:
unnamed: TOUCH.4, TO_PAD.1
unnamed: ACCEL.1, C401.2, MICRO.1, PWR_IN.1, Q401.E, TOUCH.1
unnamed: ACCEL.2, C402.2, MICRO.2, Q401.C, TOUCH.2
unnamed: LED3.A, MICRO.4
unnamed: LED2.A, MICRO.5
unnamed: LED1.A, MICRO.6
unnamed: ACCEL.3, C401.1, C402.1, LED1.C@4 (C), LED2.C@4 (C), LED3.C@4 (C), MICRO.3, PWR_IN.2, Q401.B, TOUCH.3

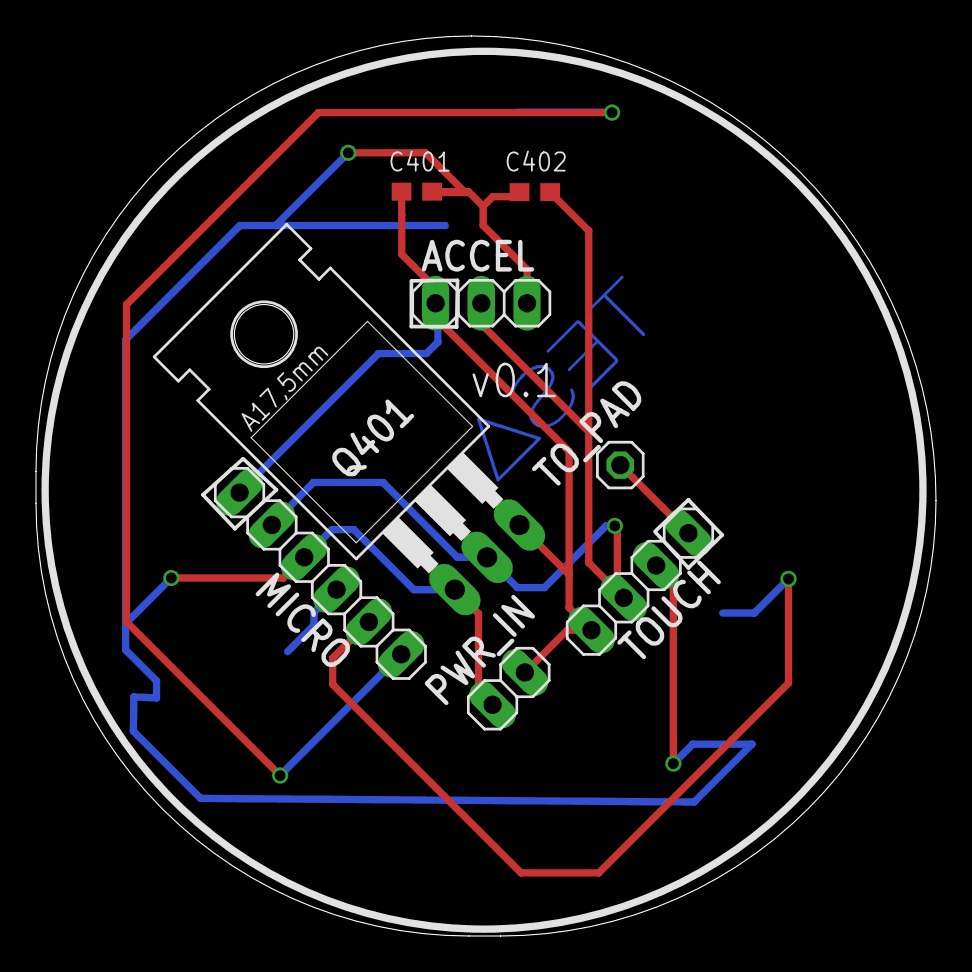
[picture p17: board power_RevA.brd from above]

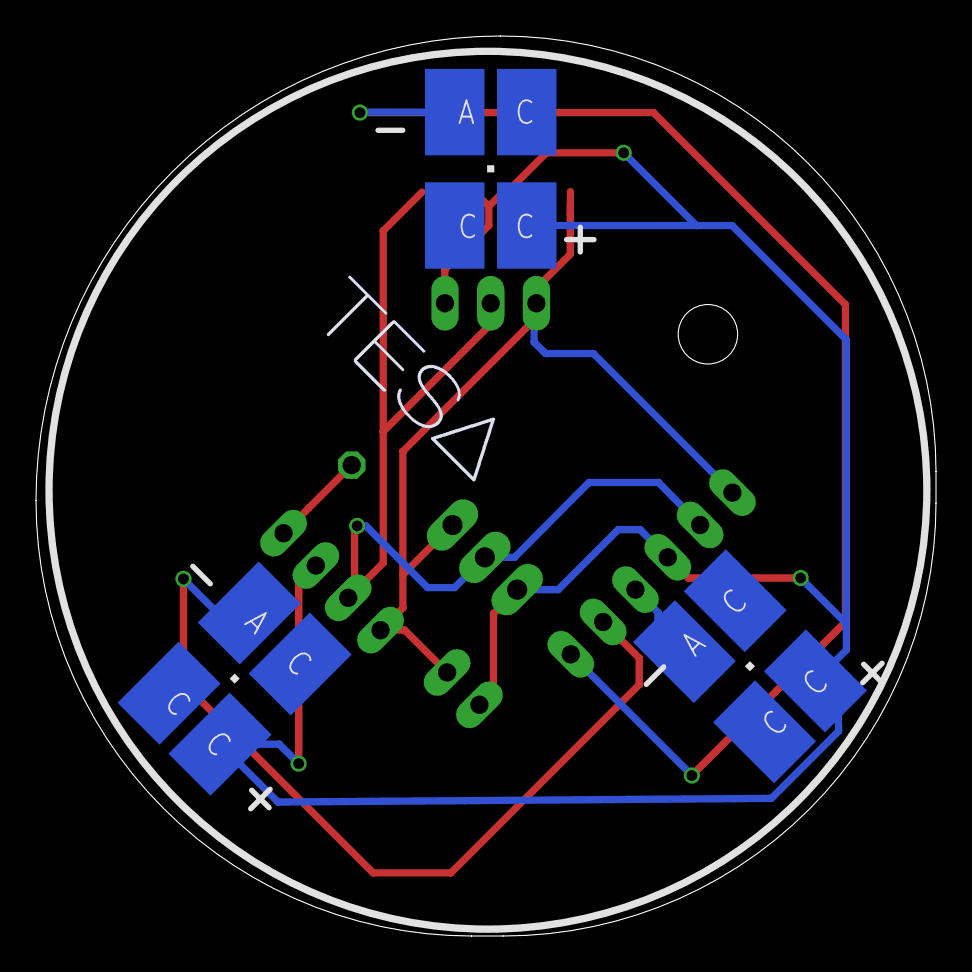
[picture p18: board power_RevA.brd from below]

Board: 2 copper layers, 50.0 x 50.0 mm, 11 parts (3 on the bottom side), 7 nets.

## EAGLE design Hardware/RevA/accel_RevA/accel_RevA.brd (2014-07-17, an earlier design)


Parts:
C1, C2: 0.1u; C0603
C3: 4.7u; C0603
INTS: PINHD-1X2; 1X02
LED1, LED2, LED3: LEDP-LCC-4; P-LCC-4
MICRO: PINHD-1X5; 1X05
PWR: PINHD-1X3; 1X03
TOUCH: PINHD-1X1; 1X01
TO_PAD: PINHD-1X1; 1X01
U1: MMA8452Q; QFN-16_0.5MM

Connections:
GND: C1.1, C2.2, C3.2, PWR.2, U1.5 (GND), U1.10 (GND), U1.12 (GND)
LED1: LED1.C@4 (C), MICRO.3
LED2: LED2.C@4 (C), MICRO.4
LED3: LED3.C@4 (C), MICRO.5
unnamed: INTS.1, U1.11 (INT1)
unnamed: INTS.2, U1.9 (INT2)
unnamed: C1.2, U1.2 (BYP)
SCL: MICRO.2, U1.4 (SCL)
SDA: MICRO.1, U1.6 (SDA)
TOUCH: TOUCH.1, TO_PAD.1
VCC: C2.1, C3.1, PWR.3, U1.1 (VDDIO), U1.14 (VDD)
VDD: LED1.A, LED2.A, LED3.A, PWR.1



Board: 2 copper layers, 49.9 x 50.0 mm, 12 parts (3 on the bottom side), 12 nets.

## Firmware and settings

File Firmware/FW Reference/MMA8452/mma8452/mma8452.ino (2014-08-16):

/* 
 MMA8452Q Basic Example Code
 Nathan Seidle
 SparkFun Electronics
 November 5, 2012
 
 License: This code is public domain but you buy me a beer if you use this and we meet someday (Beerware license).
 
 This example code shows how to read the X/Y/Z accelerations and basic functions of the MMA5842. It leaves out
 all the neat features this IC is capable of (tap, orientation, and inerrupts) and just displays X/Y/Z. See 
 the advanced example code to see more features.
 
 Hardware setup:
 MMA8452 Breakout ------------ Arduino
 3.3V --------------------- 3.3V
 SDA -------^^(330)^^------- A4
 SCL -------^^(330)^^------- A5
 GND ---------------------- GND
 
 The MMA8452 is 3.3V so we recommend using 330 or 1k resistors between a 5V Arduino and the MMA8452 breakout.
 
 The MMA8452 has built in pull-up resistors for I2C so you do not need additional pull-ups.
 */

#include <Wire.h> // Used for I2C

// The SparkFun breakout board defaults to 1, set to 0 if SA0 jumper on the bottom of the board is set
#define MMA8452_ADDRESS 0x1D  // 0x1D if SA0 is high, 0x1C if low

//Define a few of the registers that we will be accessing on the MMA8452
#define OUT_X_MSB 0x01
#define XYZ_DATA_CFG  0x0E
#define WHO_AM_I   0x0D
#define CTRL_REG1  0x2A

#define GSCALE 2 // Sets full-scale range to +/-2, 4, or 8g. Used to calc real g values.

void setup()
{
  Serial.begin(57600);
  Serial.println("MMA8452 Basic Example");

  Wire.begin(); //Join the bus as a master

  initMMA8452(); //Test and intialize the MMA8452
}

void loop()
{  
  int accelCount[3];  // Stores the 12-bit signed value
  readAccelData(accelCount);  // Read the x/y/z adc values

  // Now we'll calculate the accleration value into actual g's
  float accelG[3];  // Stores the real accel value in g's
  for (int i = 0 ; i < 3 ; i++)
  {
    accelG[i] = (float) accelCount[i] / ((1<<12)/(2*GSCALE));  // get actual g value, this depends on scale being set
  }

  // Print out values
  for (int i = 0 ; i < 3 ; i++)
  {
    Serial.print(accelG[i], 4);  // Print g values
    Serial.print("\t");  // tabs in between axes
  }
  Serial.println();

  delay(10);  // Delay here for visibility
}

void readAccelData(int *destination)
{
  byte rawData[6];  // x/y/z accel register data stored here

  readRegisters(OUT_X_MSB, 6, rawData);  // Read the six raw data registers into data array

  // Loop to calculate 12-bit ADC and g value for each axis
  for(int i = 0; i < 3 ; i++)
  {
    int gCount = (rawData[i*2] << 8) | rawData[(i*2)+1];  //Combine the two 8 bit registers into one 12-bit number
    gCount >>= 4; //The registers are left align, here we right align the 12-bit integer

    // If the number is negative, we have to make it so manually (no 12-bit data type)
    if (rawData[i*2] > 0x7F)
    {  
      gCount = ~gCount + 1;
      gCount *= -1;  // Transform into negative 2's complement #
    }

    destination[i] = gCount; //Record this gCount into the 3 int array
  }
}

// Initialize the MMA8452 registers 
// See the many application notes for more info on setting all of these registers:
// http://www.freescale.com/webapp/sps/site/prod_summary.jsp?code=MMA8452Q
void initMMA8452()
{
  byte c = readRegister(WHO_AM_I);  // Read WHO_AM_I register
  Serial.println("initialized");
  if (c == 0x2A) // WHO_AM_I should always be 0x2A
  {  
    Serial.println("MMA8452Q is online...");
  }
  else
  {
    Serial.print("Could not connect to MMA8452Q: 0x");
    Serial.println(c, HEX);
    while(1) ; // Loop forever if communication doesn't happen
  }

  MMA8452Standby();  // Must be in standby to change registers

  // Set up the full scale range to 2, 4, or 8g.
  byte fsr = GSCALE;
  if(fsr > 8) fsr = 8; //Easy error check
  fsr >>= 2; // Neat trick, see page 22. 00 = 2G, 01 = 4A, 10 = 8G
  writeRegister(XYZ_DATA_CFG, fsr);

  //The default data rate is 800Hz and we don't modify it in this example code

  MMA8452Active();  // Set to active to start reading
}

// Sets the MMA8452 to standby mode. It must be in standby to change most register settings
void MMA8452Standby()
{
  byte c = readRegister(CTRL_REG1);
  writeRegister(CTRL_REG1, c & ~(0x01)); //Clear the active bit to go into standby
}

// Sets the MMA8452 to active mode. Needs to be in this mode to output data
void MMA8452Active()
{
  byte c = readRegister(CTRL_REG1);
  writeRegister(CTRL_REG1, c | 0x01); //Set the active bit to begin detection
}

// Read bytesToRead sequentially, starting at addressToRead into the dest byte array
void readRegisters(byte addressToRead, int bytesToRead, byte * dest)
{
  Wire.beginTransmission(MMA8452_ADDRESS);
  Wire.write(addressToRead);
  Wire.endTransmission(false); //endTransmission but keep the connection active

  Wire.requestFrom(MMA8452_ADDRESS, bytesToRead); //Ask for bytes, once done, bus is released by default

  while(Wire.available() < bytesToRead); //Hang out until we get the # of bytes we expect

  for(int x = 0 ; x < bytesToRead ; x++)
    dest[x] = Wire.read();    
}

// Read a single byte from addressToRead and return it as a byte
byte readRegister(byte addressToRead)
{
  Wire.beginTransmission(MMA8452_ADDRESS);
  Wire.write(addressToRead);
  Wire.endTransmission(false); //endTransmission but keep the connection active

  Wire.requestFrom(MMA8452_ADDRESS, 1); //Ask for 1 byte, once done, bus is released by default

  while(!Wire.available()) ; //Wait for the data to come back
  return Wire.read(); //Return this one byte
}

// Writes a single byte (dataToWrite) into addressToWrite
void writeRegister(byte addressToWrite, byte dataToWrite)
{
  Wire.beginTransmission(MMA8452_ADDRESS);
  Wire.write(addressToWrite);
  Wire.write(dataToWrite);
  Wire.endTransmission(); //Stop transmitting
}

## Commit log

2014-05-13 Preliminary pricing estimates
    Pricing for electronics for run of 100.
    [PricingFor100.xlsx]
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2014-05-23 Pricing 2.0
    Pricing added for accelerometer. New sheet showing pricing for USB
    compatible model.
    [PricingFor100.xlsx]
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2014-05-23 accel_RevA: Complete* schematic and board begin
    *Some revisions may be necessary!! Board only has components placed, no
    traces of design rules.
    [accel_RevA.brd, accel_RevA.sch]
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2014-05-24 Update of accel board and schem
    Moved about stuff, added silkscreen cut guide, removed pullups on I2C (
    will be included on microcontroller )
    [accel_RevA.sch]
2014-05-24 Update of revA of accel board
    Completed routing of board!! No rats nest left, passes DRC and ERC.
    [accel_RevA.brd, accel_RevA.sch]
2014-05-24 Added names to stuff on board
    Just the names and stuff, not really much. Just needs some legit
    artwork.
    [accel_RevA.brd]
2014-05-24 TouchBoardSchematic
    Added touch board schematic; be careful of difference between VCC net
    and VDD net.
    [TouchBoardSchematic.sch]
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2014-05-25 Reworked micro schem/board
    Schem complete, beginning routing.
    [micro_RevA.brd, micro_RevA.sch]
2014-05-25 Readme changes, update to micro board
    Added trace sizing to readme, began running traces for micro board (it's
    busy).
    [micro_RevA.brd]
2014-05-25 WOW!! Almost forgot to connect data and clk lines
    Good to catch the stupid shit early on.
    [micro_RevA.brd, micro_RevA.sch]
2014-05-26 Updated touch schem
    Some fixes: removed pull up res, pulled rst high, should probably add a
    pin out for change line for debugging, resistor values needed.
2014-05-28 Completed routing of microcontroller board
    Everything is routed and passes drc. Still needs visual inspection.
    [micro_RevA.brd, micro_RevA.sch]
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2014-05-31 Finished micro and adjusted text of accel
    MUST CHECK THAT TPLACE IS ON SILSCREEN OR SHIT!!!
    [Attempt1.brd, Attempt1.sch, LAYOUT.brd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]
2014-05-31 TouchBoard
    Labeled the board with silkscreened names for components and headers.
    [TouchBoardSchematic.brd]
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2014-06-05 Added labels, resized boundary
    Everything is labeled now, but the boards needs to be placed in the 5cm
    by 5cm boundary. The vias leave their holes behind though....
    [Power_RevA.brd, Power_RevA.sch]
2014-06-05 Added RevA gerbers, not ordered yet! Still draft
    Each board has a set of files required for manufacturing called gerbers.
    These are the files we will review to be sure they are perfect. If these
    are wrong in any way it makes things much more interesting to figure out
    and proceed. Each board has its own folder.
    [Power_RevA.GBL, Power_RevA.GBO, Power_RevA.GBP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]
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2014-06-07 An excel spread sheet BOM
    It is hilarious that ain't no one heard BOM before! This is what sets us
    apart from s/w (well, and everything else h/w...). This is still in
    progress and the way it is formatted will be super helpful for assembly.
    [BOM.xlsx]
2014-06-10 Power and Touch Board LED Orientation Fixed
    The touch board is sill routed incorrectly (schematic is wrong too) but
    orientation is silk-screened on board. Power board is routed absolutely
    correctly.
    [Power_RevA.brd, Power_RevA.sch, TouchBoardSchematic.brd]
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2014-06-13 Updates on BOM, and shit on the design
    Added order locations and discovered that mouser and digikey are out of
    atmega32u4s. Straight up fuck! They don't get any for months. Last
    minute redesign? Pay a shit ton more and get them from
    sparkfun/adafruit, or are they out too?! Maybe this is a world wide
    shortage. People can't get their hands on built in usb support and
    engineers all over fucking everywhere are killing each other to get
    their oily hands all over these sleek, sexy chips. I would kill a man to
    hold one right now, and then another man to keep it forever. Okay,
    bedtime.
    [BOM.xlsx]
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2014-06-23 Centered it to fit in 5cm x 5cm
    And am going to CAM it.
    [Power_RevA.GBL, Power_RevA.GBO, Power_RevA.GBP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]
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2014-06-24 Added a bunch of gerbers, and some minor changes
    And a bunch of pictures of gerbers
    [Power_RevA.GBL, Power_RevA.GBO, Power_RevA.GBP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]
2014-06-24 Added circle outline in correct layers
    To power board
    [BOM.xlsx, Power_RevA.brd]
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2014-07-10 Changes to the BOM; very near completion
    Added individual BOM files for each board -> I find it summarises things
    a bit better. Power is not complete yet. Other than that the only thing
    missing is the supplier info for the LEDs.
    [accelBOM-RevA.xlsx, microBOM-RevA.xlsx, powerBOM-RevA.xlsx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]
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2014-07-16 Micro BOM fixes
    Some part number errors corrected
    [microBOM-RevA.xlsx]
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2014-07-16 Added Javen's logo to everything
    Still need to add plus/minus on leds before order.
    [Power_RevA.GBL, Power_RevA.GBO, Power_RevA.GBP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]
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2014-07-17 Update of hw files
    Added logo to brds, added +/- to LEDs and generated and updated gerber
    files.
    [Power_RevA.GBL, Power_RevA.GBO, Power_RevA.GBP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]
2014-07-22 Added cost folder
    Includes order cost summaries -> Itead being the only critical one for
    reimbursement
    [Adafruit2IDorder.xlsx, AdafruitIDorder.xlsx, FastTechIDorder.xlsx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]
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2014-08-01 Started FW, moved RevA designs to a RevA folder
    Began a list of desired improvements for RevB. Let's learn from our
    mistakes! The FW contains functions pertaining to the LED driver. Mostly
    lower level functions, I tried thinking about the best way to do the
    rotation dimming idea, but it hurt my head so I ground out the barebones
    of the LED driver source code.
    [accel_RevA.brd, accel_RevA.sch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]
2014-08-02 Continuing work on LED driver code
    Still not working.... I broke the code up into header files. Which makes
    it much nicer to read, however, OO was the only way to go and I'm afraid
    that it generates longer code. Will need to investigate this. Can light
    an arbitrary selection of LEDs on, don't know why some are off, can't
    turn them off. Much work yet to be done.
2014-08-12 BOM corrections and update rev
    The power BOM was completely wrong, so I re-made it; the others just had
    their boards and revs updated
    [microBOM-RevA.xlsx, powerBOM-RevA.xlsx, touchBOM-RevA.xlsx]
2014-08-13 Made an inventory and acquisitions list
    New directory for inventory and acquisitions! This must be updated every
    time a component is used!!!!!!! Moved the previous orders to a new
    directory in the hope they will never be copied. readme updated.
    [Master Acquisitions.xlsx, Master Inventory.xlsx, microBOM-RevA.xlsx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]
2014-08-13 Added the TLC59711 everywhere!!
    We missed it. We should all feel somewhat ashamed to have missed such an
    obvious omission. Some minor changes to inventory list as well.
    [BOM.xlsx, Master Acquisitions.xlsx, Master Inventory.xlsx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]
2014-08-16 Meeting 15 August
    New example FW!!! Moved the TLC example into a subdir to clarify
    things. Discovered we don't have any 4.7u caps. More stuff that managed
    to slip through the cracks.
    [Master Acquisitions.xlsx, accelBOM-RevA.xlsx]
2014-08-16 Inventory update
    Should really be done immediately after parts are used, but Adam is
    having trouble figuring out github.
    [Master Inventory.xlsx]
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2014-09-24 Hardware focussed changes
    Added schem and brd files for RevB of the micro-controller, updated
    acquisitions and inventory and, like the idiot I am, downloaded the same
    datasheet and then decided I liked that name better.
    [Master Acquisitions.xlsx, Master Inventory.xlsx, micro_RevB-328.brd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]
2014-10-01 inventory update; TLC pin defs changed
    I changed what port on the TLC59711 goes to which board to make routing
    the Micro RevB easier. Tried to make an Accel, but there appears to be
    shorts....
    [Master Inventory.xlsx]
2014-10-02 Routing micro RevB
    micro RevB is about half routed; schematic had a few errors corrected;
    added a notes file to keep track of the things to be kept standard.
    [micro_RevB-328.brd, micro_RevB-328.sch]
2014-10-03 Progress on routing micron RevB
    Done routing; working on the silkcreening; probably changing the ADC
    individual pins to a 5 pin header.
    [micro_RevB-328.brd, micro_RevB-328.sch]
2014-10-18 Working on keeping things organized
    Updates to acquisition list for RevB of micro board; update to inventory
    to reflect what we have
    [Master Acquisitions.xlsx, Master Inventory.xlsx]
2014-10-22 Note to self...
    Added a note in acquisitions to add LEDs when I have more time.
    [Master Acquisitions.xlsx]
2014-10-29 Order components for RevB Micro
    Updates to acquisitions to reflect ordered components; added the order
    to the expenses folder
    [Master Acquisitions.xlsx]
2014-11-05 A good day of work!
    Assembled a RevB micro, have not yet tested; started making a list of
    what I did wrong in this one (stupid me, I forgot the logo, pin 1
    designations); readme contains info about jumper resistors used on the
    board
    [Master Acquisitions.xlsx, Master Inventory.xlsx]
2014-11-10 Partial build of a board
    Updated inventory to reflect components used: a very good habit that I'm
    trying to develop.
    [Master Inventory.xlsx]
2014-11-12 Update to inventory; added a FW design doc
    Also, removed some crappy experimentations I had done for FW.
    [Master Inventory.xlsx]
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

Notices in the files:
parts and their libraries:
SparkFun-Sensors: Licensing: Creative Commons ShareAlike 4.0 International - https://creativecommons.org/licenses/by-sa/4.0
